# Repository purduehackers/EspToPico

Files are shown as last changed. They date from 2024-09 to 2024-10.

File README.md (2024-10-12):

# EspToPico
This is a converter board for an ESP32 to a Pi Pico for the purposes of the Sign Project.

The next revision of the board (3) should fix the following problems:
- It is impossible to program the board without resorting to using the bodged boot button. The official ESP32 dev board uses the serial chip to reset the ESP32 and put it in boot mode. Schematics are available online. This would be ideal.
- The button switch and LED lines had to be reversed here since the LED line was sent to an input-only pin. I reversed the labels for rev 2, but now there is a mismatch to the motherboard. This could be fixed later but it doesn't matter very much.
- The EEPROM MOSI, SCK, and CS lines are assigned to an input-only pin, rendering the EEPROM inaccessible. The ESP32 has enough storage to make this a non-issue, but it is still a problem. The easiest fix would be to switch the EEPROM MISO and MOSI lines then move the SCK and CS lines to regular GPIOs like GPIO 2 and 13.

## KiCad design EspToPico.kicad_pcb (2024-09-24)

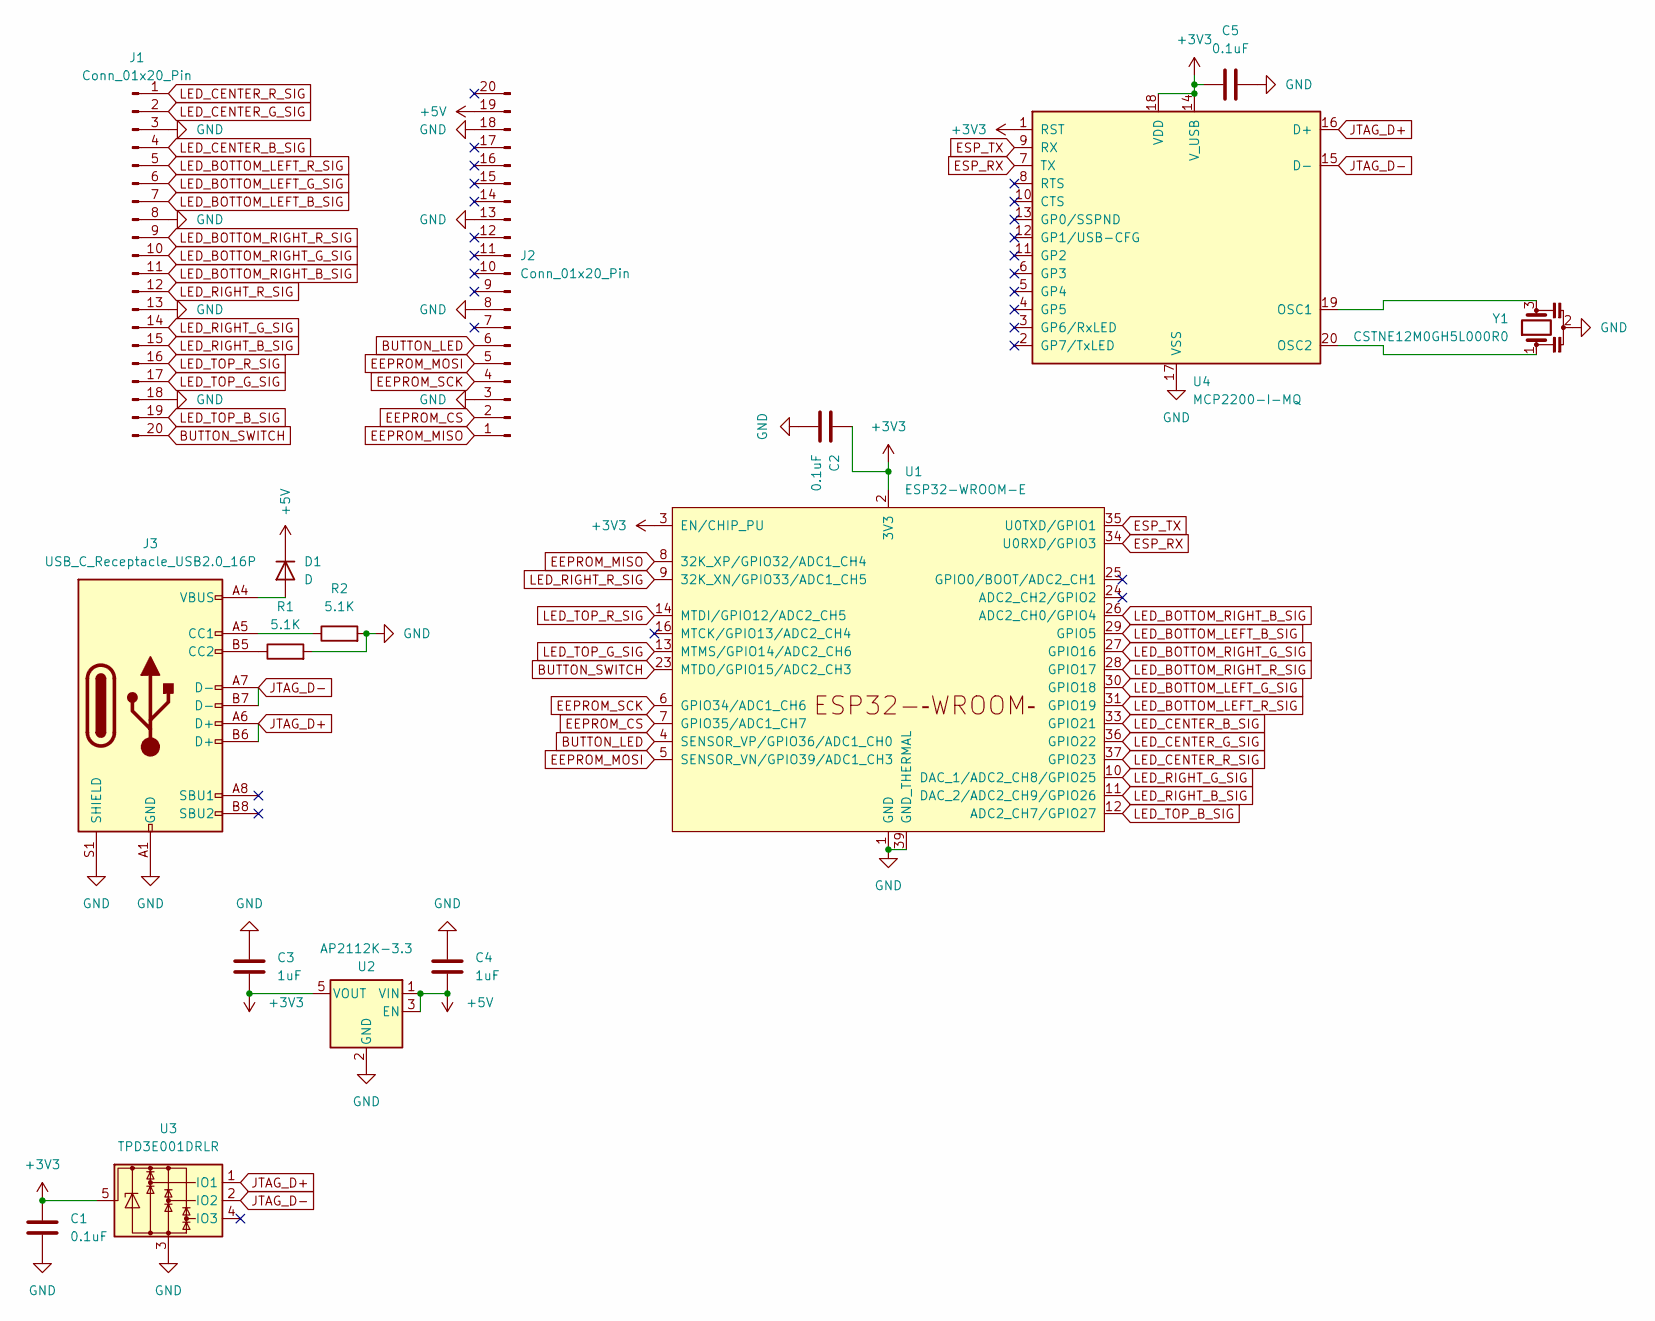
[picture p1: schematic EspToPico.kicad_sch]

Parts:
C1, C2: 0.1uF; C_0402_1005Metric
C3, C4: 1uF; C_0402_1005Metric
C5: 0.1uF
D1: D; D_SOD-323; LCSC C78740
J1, J2: Conn_01x20_Pin; PinHeader_1x20_P2.54mm_Vertical
J3: USB_C_Receptacle_USB2.0_16P; USB_C_Receptacle_GCT_USB4105-xx-A_16P_TopMnt_Horizontal; LCSC C2835315
R1, R2: 5.1K; R_0402_1005Metric
U1: ESP32-WROOM-E; ESP32-WROOM-32E
U2: AP2112K-3.3; SOT-23-5
U3: TPD3E001DRLR; SOT-553; LCSC C470828
U4: MCP2200-I-MQ; QFN-20-1EP_5x5mm_P0.65mm_EP3.35x3.35mm
Y1: CSTNE12M0GH5L000R0; CSTCE12M0G15L

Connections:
+3V3: C1.1, C2.1, C3.2, C5.1, U1.2 (3V3), U1.3 (EN/CHIP_PU), U2.5 (VOUT), U3.5, U4.1 (RST), U4.14 (V_USB), U4.18 (VDD)
+5V: C4.2, D1.1 (K), J2.19, U2.1 (VIN), U2.3 (EN)
BUTTON_LED: J2.6, U1.4 (SENSOR_VP/GPIO36/ADC1_CH0)
BUTTON_SWITCH: J1.20, U1.23 (MTDO/GPIO15/ADC2_CH3)
EEPROM_CS: J2.2, U1.7 (GPIO35/ADC1_CH7)
EEPROM_MISO: J2.1, U1.8 (32K_XP/GPIO32/ADC1_CH4)
EEPROM_MOSI: J2.5, U1.5 (SENSOR_VN/GPIO39/ADC1_CH3)
EEPROM_SCK: J2.4, U1.6 (GPIO34/ADC1_CH6)
ESP_RX: U1.34 (U0RXD/GPIO3), U4.7 (TX)
ESP_TX: U1.35 (U0TXD/GPIO1), U4.9 (RX)
GND: C1.2, C2.2, C3.1, C4.1, C5.2, J1.3, J1.8, J1.13, J1.18, J2.3, J2.8, J2.13, J2.18, J3.A1 (GND), J3.A12 (GND), J3.B1 (GND), J3.B12 (GND), J3.S1 (SHIELD), R1.2, R2.2, U1.1 (GND), U1.15 (GND), U1.38 (GND), U1.39 (GND_THERMAL), U2.2 (GND), U3.3, U4.17 (VSS), Y1.2
JTAG_D+: J3.A6 (D+), J3.B6 (D+), U3.1 (IO1), U4.16 (D+)
JTAG_D-: J3.A7 (D-), J3.B7 (D-), U3.2 (IO2), U4.15 (D-)
LED_BOTTOM_LEFT_B_SIG: J1.7, U1.29 (GPIO5)
LED_BOTTOM_LEFT_G_SIG: J1.6, U1.30 (GPIO18)
LED_BOTTOM_LEFT_R_SIG: J1.5, U1.31 (GPIO19)
LED_BOTTOM_RIGHT_B_SIG: J1.11, U1.26 (ADC2_CH0/GPIO4)
LED_BOTTOM_RIGHT_G_SIG: J1.10, U1.27 (GPIO16)
LED_BOTTOM_RIGHT_R_SIG: J1.9, U1.28 (GPIO17)
LED_CENTER_B_SIG: J1.4, U1.33 (GPIO21)
LED_CENTER_G_SIG: J1.2, U1.36 (GPIO22)
LED_CENTER_R_SIG: J1.1, U1.37 (GPIO23)
LED_RIGHT_B_SIG: J1.15, U1.11 (DAC_2/ADC2_CH9/GPIO26)
LED_RIGHT_G_SIG: J1.14, U1.10 (DAC_1/ADC2_CH8/GPIO25)
LED_RIGHT_R_SIG: J1.12, U1.9 (32K_XN/GPIO33/ADC1_CH5)
LED_TOP_B_SIG: J1.19, U1.12 (ADC2_CH7/GPIO27)
LED_TOP_G_SIG: J1.17, U1.13 (MTMS/GPIO14/ADC2_CH6)
LED_TOP_R_SIG: J1.16, U1.14 (MTDI/GPIO12/ADC2_CH5)
unnamed: D1.2 (A), J3.A4 (VBUS), J3.A9 (VBUS), J3.B4 (VBUS), J3.B9 (VBUS)
unnamed: J3.A5 (CC1), R2.1
unnamed: J3.B5 (CC2), R1.1
unnamed: U4.19 (OSC1), Y1.3
unnamed: U4.20 (OSC2), Y1.1

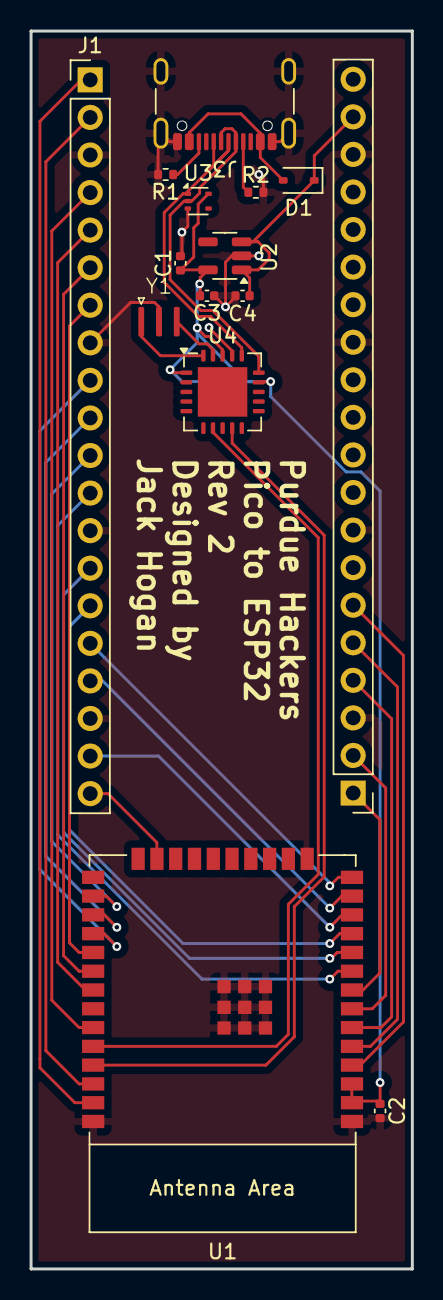
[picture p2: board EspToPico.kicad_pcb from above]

Board: 2 copper layers, 25.8 x 83.7 mm, 15 parts (0 on the bottom side), 33 nets.

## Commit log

2024-08-24 Removed sleep depravation
    [EspToPico.kicad_sch]
2024-08-26 Added capacitors to the voltage regulator, added through-hole to the ESP32 for hand-soldering, and updated some routing.
    [EspToPico.kicad_pcb, EspToPico.kicad_sch]
2024-09-23 Started conversion to ESP32
    [EspToPico.kicad_pcb, EspToPico.kicad_sch]
2024-09-24 Updated to ESP32
    [EspToPico.kicad_pcb, EspToPico.kicad_sch]
2024-09-24 Fixed silkscreen
    [EspToPico.kicad_pcb]
2024-09-24 Electrical and Routing fixes
    [EspToPico.kicad_pcb, EspToPico.kicad_sch]
2024-10-12 Reversed button switch and LED pins since the original LED pin is input only
    [EspToPico.kicad_sch]
